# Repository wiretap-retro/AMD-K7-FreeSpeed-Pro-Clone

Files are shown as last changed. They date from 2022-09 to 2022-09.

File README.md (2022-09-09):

# AMD K7 FreeSpeed Pro Clone
This device attaches to the AMD K7 debug port and provides for overclocking. It is a clone of the FreeSpeed Pro by Ninja Micros.

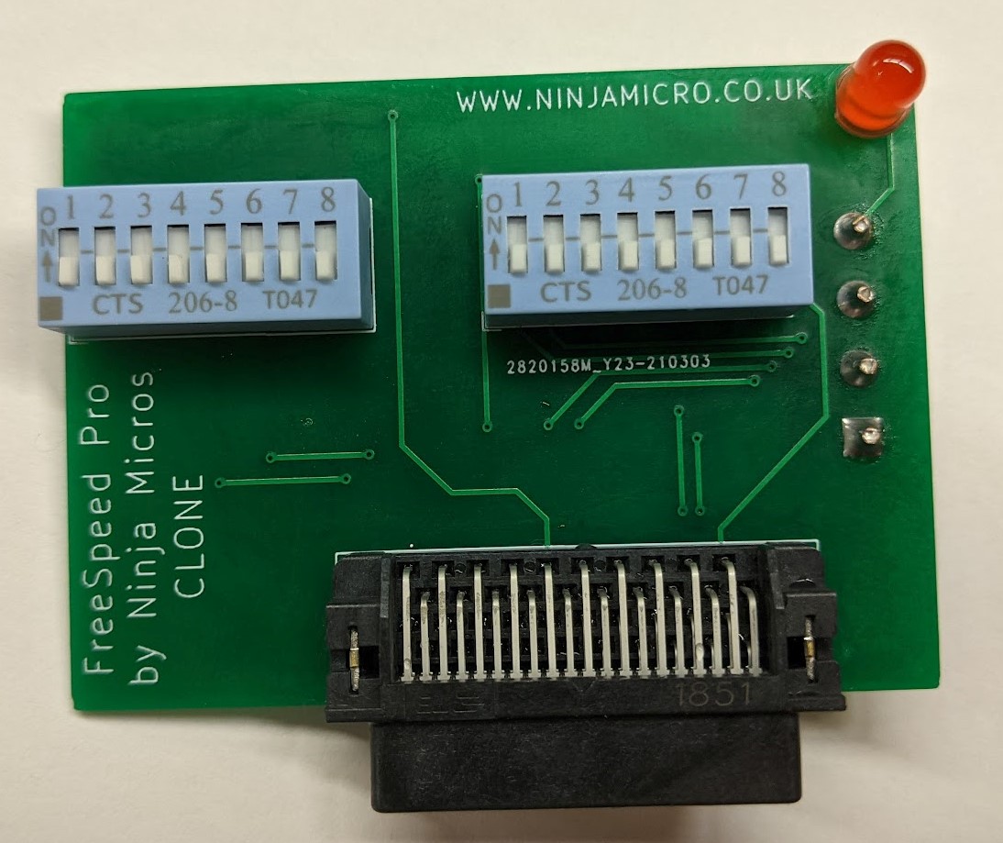
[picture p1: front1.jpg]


## Vogons.org Project
URL: https://www.vogons.org/viewtopic.php?t=71328

## Project Status
Tested and working by numerous people. Results may vary based on CPU and motherboard support.

## Building / Installing
This repository contains the KiCAD files, Gerbers, BOM and Pick & Place files. The BOM and Pick & Place files are formatted for JLCPCB assembly. They can be directly uploaded along with the Gerbers for their SMT assembly service. Parts subsitutions may be required if certain components are out of stock due to component/chip shortages. Through-hole components are to be soldered after you receive the board from JLCPCB.
* If performing assembly the assembly entirely by hand, solder all SMD components on the back first, along with the 4-pin molex connector.
* Next, solder the dip switches, socket connector, and LED. That's it!
* Refer to the Ninjamicro Jumper Settings picture in the repository to set your DIP switches properly. Don't start out with too aggressive of an overclock.
* On your AMD K7 CPU, open the casing to expose the debug connector.
* Plug the FreeSpeed device into the connector and attach a 4-pin molex cable.
* Test boot the machine and have fun.

## Optional
You can cut the AMD K7's housing with a pair of side cutters and file to make the FreeSpeed Pro fit while the shroud is installed. Measure twice, cut once. 

## Miscellaneous
This is an open hardware design, so do what you want with it. I tried contacting the original creator through all points of contact I could find, and there was no answer back. There are no copyright, trademark, or registration marks on the original device and the website no longer exists. This device also very closely matches the schematics in the Tom's Hardware article from November 13th, 1999 titled "Make Your Own Athlon Overclocking Device".

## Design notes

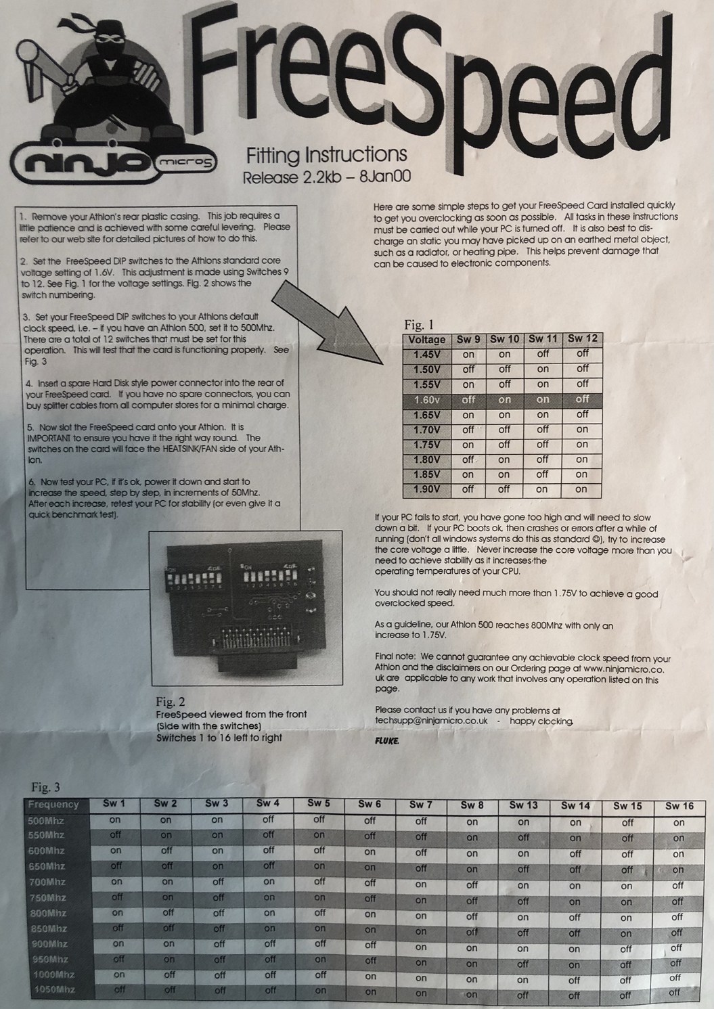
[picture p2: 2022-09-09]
Ninjamicro Jumper Settings.jpg

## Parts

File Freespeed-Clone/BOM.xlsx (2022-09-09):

Reference | Value | Manufacturer | Part # | Mouser Part # | Footprint
D1, D2 | LL4148 | ON Semiconductor | FDLL4148 | 512-FDLL4148 | SMD: Mini-MELF / LL-34 / SOD-80 / DO213-AA
D3 |  | Lite-On | LTL-4221N | 859-LTL-4221N | THT: LED 3.0mm
J1 |  | TE Connectivity | 350211-1 | 571-3502111 | THT: TE Connectivity 350211-1
J2 |  | TE Connectivity | 1734037-4 | 571-1734037-4 | THT: TE Connectivity 1734037-4
R1, R2, R3, R4, R5, R6, R7, R8, R9, R10, R11, R12, R13 | 220 Ω | KOA Speer | RK73B2BTTDD221J | 660-RK73B2BTTDD221J | SMD: Resistor 1206_3216Metric_Pad1.42x1.75mm_HandSolder
R14, R15, R16, R17, R18, R19, R20, R21 | 120 Ω | KOA Speer | RK73B2BTTDD121J | 660-RK73B2BTTDD121J | SMD: Resistor 1206_3216Metric_Pad1.42x1.75mm_HandSolder
SW1, SW2 |  | CTS Electronic Components | 206-8ST | 774-2068ST | THT: SW_DIP_SPSTx08_Slide_9.78x22.5mm_W7.62mm_P2.54mm

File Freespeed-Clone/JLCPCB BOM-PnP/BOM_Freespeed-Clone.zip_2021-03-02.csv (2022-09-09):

ID | Name | Designator | Footprint | Quantity | Manufacturer Part | Manufacturer | Supplier | Supplier Part
1 | LL4148 | D1,D2 | D_MINIMELF_HANDSOLDERING | 2
2 | LED | D3 | LED_D3.0MM | 1
3 | Conn_01x04 | J1 | SHDR4W166P0X508_1X4_2326X828X1066P | 1
4 | 1734037-4 | J2 | 17340374 | 1
5 | 220 | R1,R2,R3,R4,R5,R6,R7,R8,R9,R10,R11,R12,R13 | R_1206_3216METRIC_PAD1.42X1.75MM_HANDSOLDER | 13
6 | 120 | R14,R15,R16,R17,R18,R19,R20,R21 | R_1206_3216METRIC_PAD1.42X1.75MM_HANDSOLDER | 8
7 | SW_DIP_x08 | SW1,SW2 | SW_DIP_SPSTX08_SLIDE_9.78X22.5MM_W7.62MM_P2.54MM | 2

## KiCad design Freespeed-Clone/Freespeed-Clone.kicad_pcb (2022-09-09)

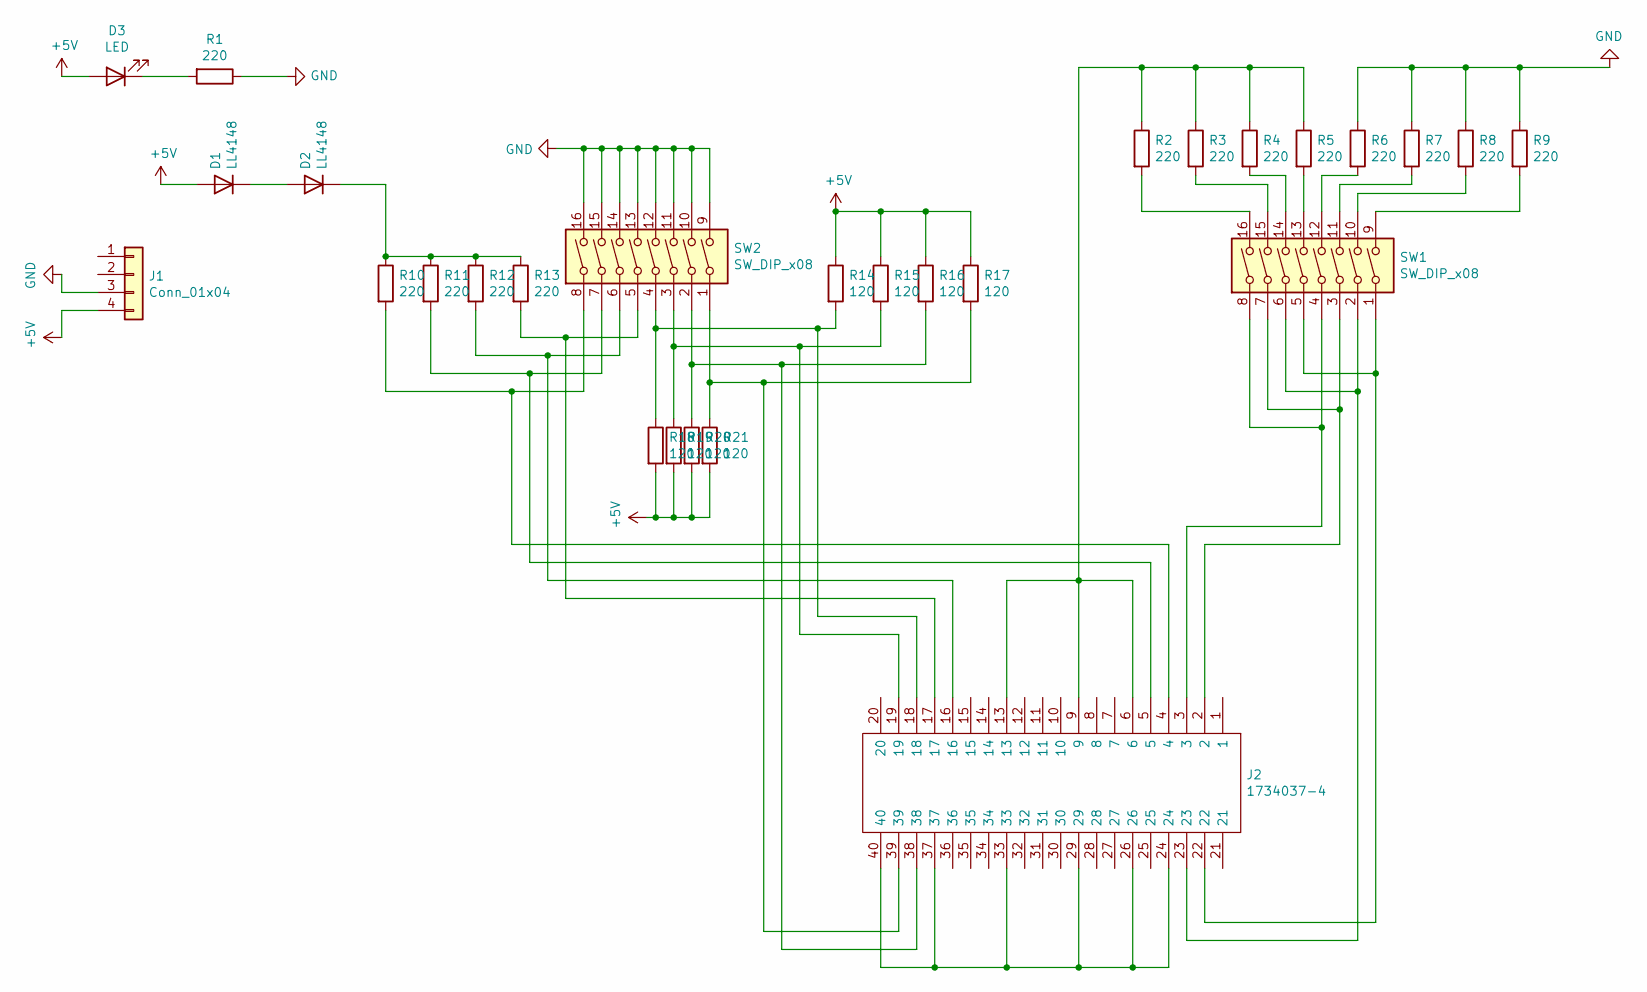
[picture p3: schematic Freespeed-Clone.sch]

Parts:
D1, D2: LL4148; D_MiniMELF_Handsoldering
D3: LED; LED_D3.0mm
J1: Conn_01x04; SHDR4W166P0X508_1X4_2326X828X1066P
J2: 1734037-4; 17340374; Mouser Part Number 571-1734037-4
R1, R2, R3, R4, R5, R6, R7, R8, R9, R10, R11, R12, R13: 220; R_1206_3216Metric_Pad1.42x1.75mm_HandSolder
R14, R15, R16, R17, R18, R19, R20, R21: 120; R_1206_3216Metric_Pad1.42x1.75mm_HandSolder
SW1, SW2: SW_DIP_x08; SW_DIP_SPSTx08_Slide_9.78x22.5mm_W7.62mm_P2.54mm

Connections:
+5V: D1.2 (A), D3.2 (A), J1.4, R14.1, R15.1, R16.1, R17.1, R18.2, R19.2, R20.2, R21.2
GND: J1.3, R1.1, R6.1, R7.1, R8.1, R9.1, SW2.9, SW2.10, SW2.11, SW2.12, SW2.13, SW2.14, SW2.15, SW2.16
unnamed: D1.1 (K), D2.2 (A)
unnamed: D2.1 (K), R10.1, R11.1, R12.1, R13.1
unnamed: D3.1 (K), R1.2
unnamed: J2.2, SW1.3, SW1.7
unnamed: J2.3, SW1.4, SW1.8
unnamed: J2.4, R10.2, SW2.8
unnamed: J2.5, R11.2, SW2.7
unnamed: J2.6, J2.9, J2.13, R2.1, R3.1, R4.1, R5.1
unnamed: J2.16, R12.2, SW2.6
unnamed: J2.17, R13.2, SW2.5
unnamed: J2.18, R14.2, R18.1, SW2.4
unnamed: J2.19, R15.2, R19.1, SW2.3
unnamed: J2.22, SW1.1, SW1.5
unnamed: J2.23, SW1.2, SW1.6
unnamed: J2.24, J2.26, J2.29, J2.33, J2.37, J2.40
unnamed: J2.38, R16.2, R20.1, SW2.2
unnamed: J2.39, R17.2, R21.1, SW2.1
unnamed: R2.2, SW1.16
unnamed: R3.2, SW1.15
unnamed: R4.2, SW1.14
unnamed: R5.2, SW1.13
unnamed: R6.2, SW1.12
unnamed: R7.2, SW1.11
unnamed: R8.2, SW1.10
unnamed: R9.2, SW1.9

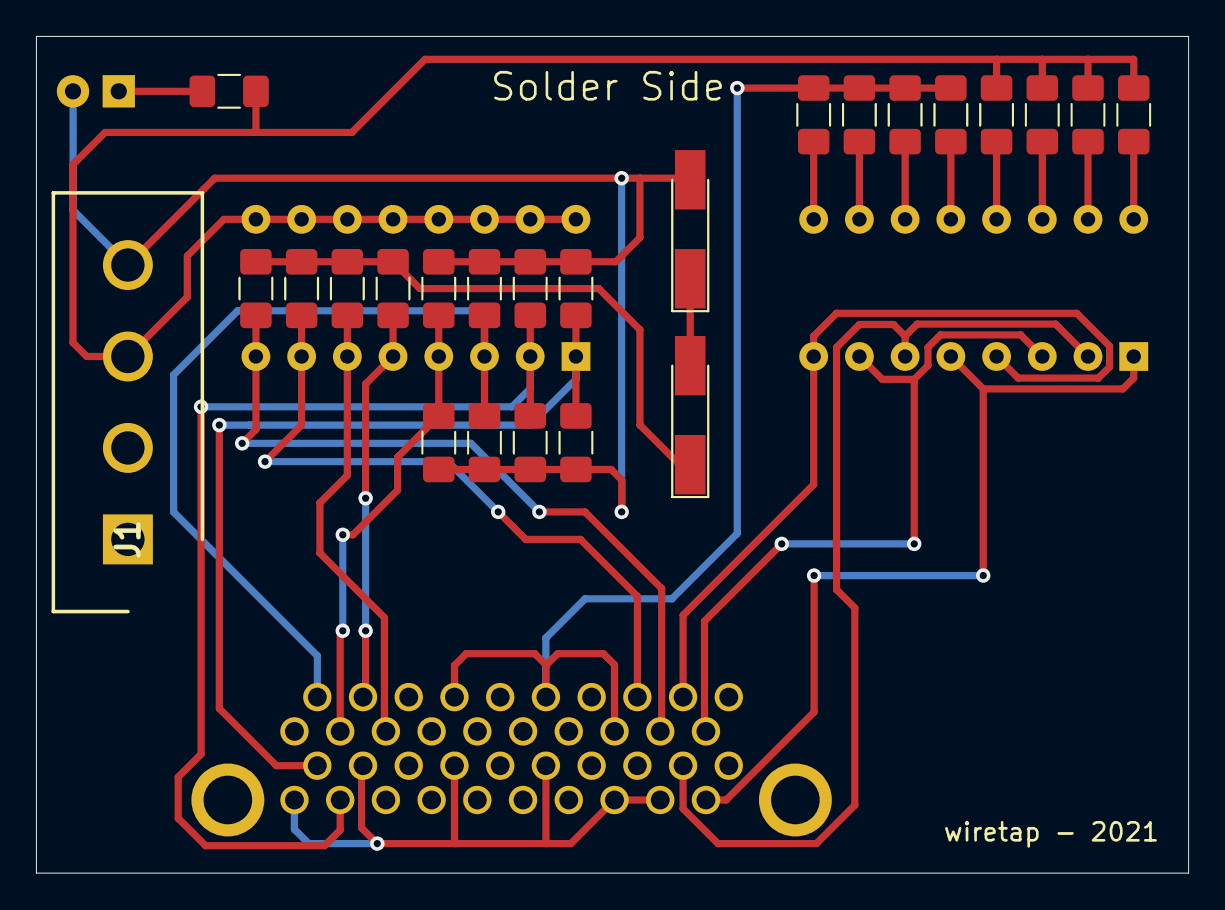
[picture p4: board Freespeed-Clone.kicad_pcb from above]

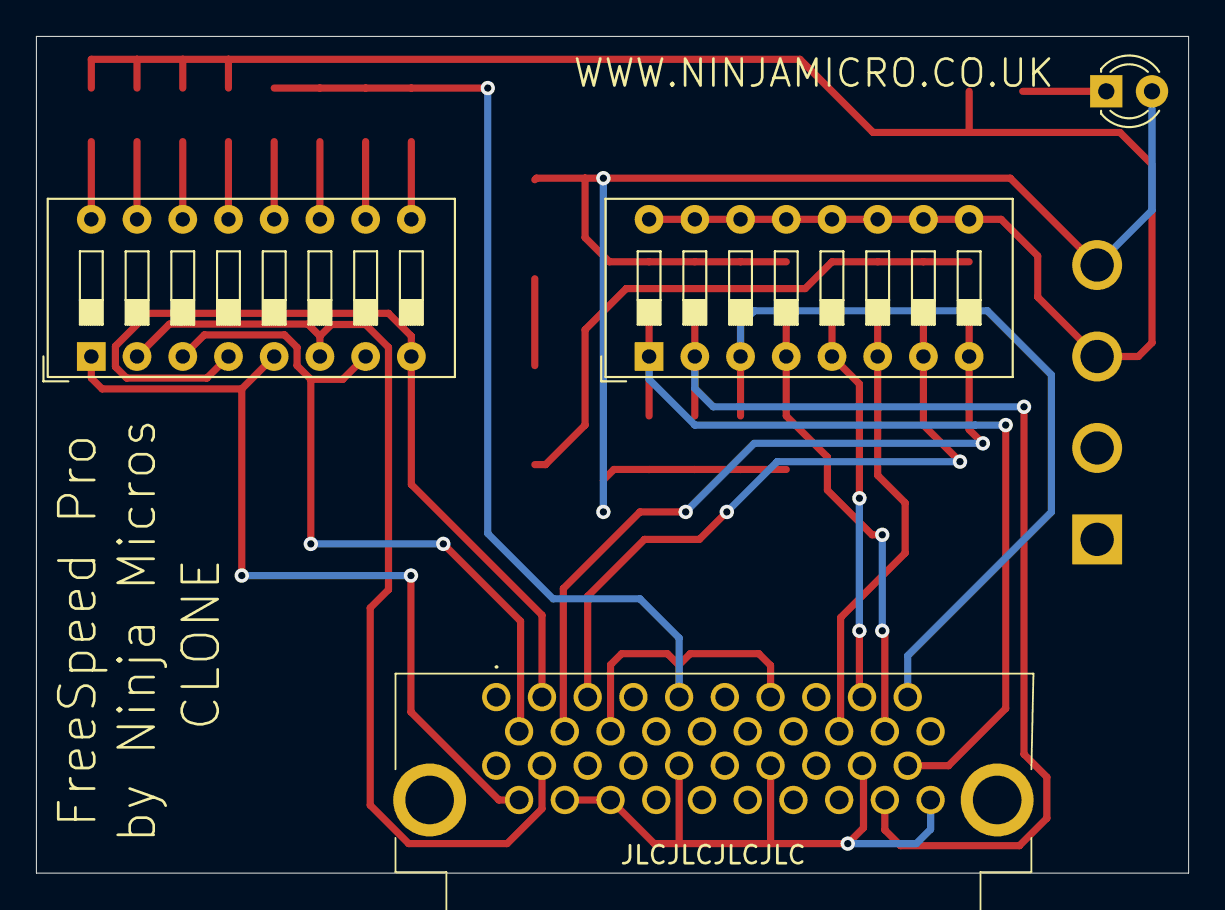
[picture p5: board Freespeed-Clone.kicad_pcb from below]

Board: 2 copper layers, 64.0 x 46.5 mm, 28 parts (4 on the bottom side), 27 nets.
